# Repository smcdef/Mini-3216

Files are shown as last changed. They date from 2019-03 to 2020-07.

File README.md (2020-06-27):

# MINI 3216 电子时钟









还记得5年前（2014年）刚入门51单片机的时候的学习场景。当年单片机的学习之路是跟着杜洋的《爱上单片机》一书学习。如今这本书都已经出到第四版了（推荐一下这本书，还是很不错的，图片和制作都很用心）。那时候就很喜欢这本书里面的电子制作。杜老师有很多的电子DIY作品，唯一让我感兴趣的就是Mini 3216。这是一个电子时钟。非常的有意思。刚学习单片机的时候就励志以后一定也做个一模一样的时钟(当年的志向就是那么的简单)。

但是当我真的开始琢磨时，发现事情并不是那么的简单。如此简单的电路是如何使用单片机的32个IO驱动 32 x 16 点阵的呢？我们知道32个IO口驱动点阵的极限是16x16点阵。很是好奇，经过自己的琢磨终于想明白了原理。我们使用32个IO口连接16x16点阵，则没有任何问题。另外16x16点阵如何处理呢？反接吧！描述的不清还是看下原理图。如果下面的原理图依然看不明白，就看下PDF的原理图（pcb/mini3216时钟V3.0.PDF）。硬件虽然是连接起来了，软件又该如何处理呢？STC单片机的IO口可以设置4种模式，分别是：普通IO、推挽输出、高祖输入和开漏。为了让一个LED的亮度正常显示，我们利用推挽输出20mA电流驱动LED。为了驱动的时候不影响其他的LED，我们还需要将不需要点亮的LED的IO口设置开漏模式。这样就OK了。

```txt
        P0 <--------+------------+
                    |   +-----+  |   +-----+
                    +---+  0  |  +---+  2  |
                        +--+--+      +--+--+
                           |            |
          +----------------+            +-------+
          |                                     |
          |  P2 <---+------------+              |
          |         |   +-----+  |   +-----+    |
          |         +---+  1  |  +---+  3  |    |
          |             +--+--+      +--+--+    |
          |                |            |       |
          +----------------+            +-------+
          |                                     |
          v                                     v
          P3                                    P4

         P3 <-------+------------+
                    |   +-----+  |   +-----+
                    +---+  4  |  +---+  6  |
                        +--+--+      +--+--+
                           |            |
          +----------------+            +-------+
          |                                     |
          |  P4 <---+------------+              |
          |         |   +-----+  |   +-----+    |
          |         +---+  5  |  +---+  7  |    |
          |             +--+--+      +--+--+    |
          |                |            |       |
          +----------------+            +-------+
          |                                     |
          v                                     v
          P0                                    P2
```

关注这款时钟实现原理的朋友，好奇的问题一定是如何驱动 32 x 16 点阵。这部分代码实现位于core/fb_core.c文件。

于是就开始了自己的DIY之旅。虽然很多年过去了，Mini 3216已经陪伴了我4个春秋。摆在电脑旁边，也是一种享受。整点时刻会小声滴滴几下，提醒着我时间的流逝。有人说电脑右下角不是有时间嘛！是啊！就当我近似看不清，我就是喜欢字体大点的😄。

而现在我依稀发现，网上还是没有人公开原理（可能感兴趣的人不多）。虽然大学毕业后并没有从事单片机行业，但是依然保持对单片机的热爱。也由于自己工作接触的软件多为开源软件。因此，自己也有一颗开源的心。希望分享给更多的人。

## 优点

1. 所有元器件都在PCB top layout，最终焊接后都会藏在点阵屏下面，美观简介。
2. 高精度时钟芯片DS3231SN，一年误差30秒之内（数据来自DS3231 Datasheet），时间更精准。
3. 支持 -20℃~60℃环境温度显示。
4. 全方位检测环境光强，环境暗时，自动降低亮度（3级亮度自动调节）。
5. 上下左右4个Micro USB接口，方便供电。
6. 具有整点报时功能，报时声音采用新闻联播7:00开始前的多段声音报时。
7. 具有独特重力换向功能，不止可以正着放，还可以倒着放，显示内容总是正向的（想象你的手机横屏功能）。
8. 内置备用电池可保证断电后上电时间依然正确。
9. 背面3个触摸按键，看起来就很高大上。
10. 主界面显示时间，每8s切换显示2s温度（如果你愿意，显示流动显示日期也不是问题啊）。
11. 5v, 40mA工作电流。粗略计算，不断电使用7个月消耗1度电。
12. 源码公开，可以愉快的DIY了。你得天下你做主。

## 效果展示

我个人是集齐了红、蓝、白、橙、绿等几种颜色。总得效果来说各个颜色都挺好看。各有特色。附上两张蓝色显示效果图。

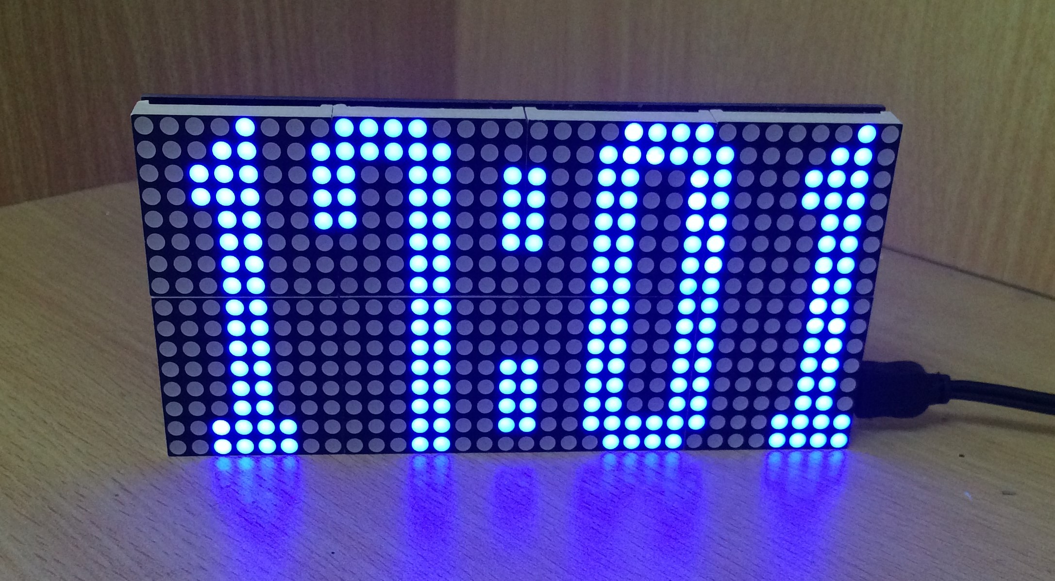
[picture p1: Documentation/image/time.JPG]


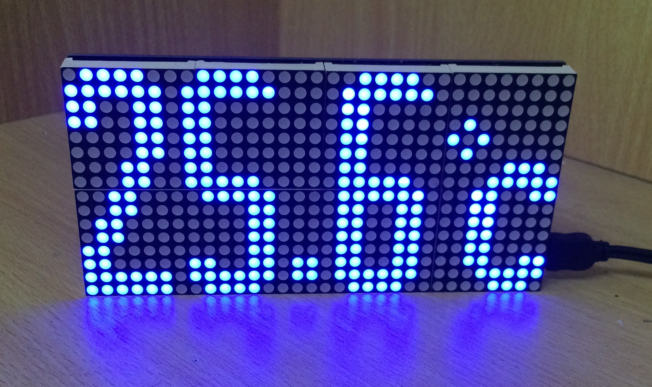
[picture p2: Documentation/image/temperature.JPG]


硬件经过几次改版，现在的硬件具有上下左右4个micro USB口，方便供电。上下左右4个光敏电阻全方位检测环境光强。背面3个触摸按键。PCB top layout 和 bottom layout 展示如下图所示。

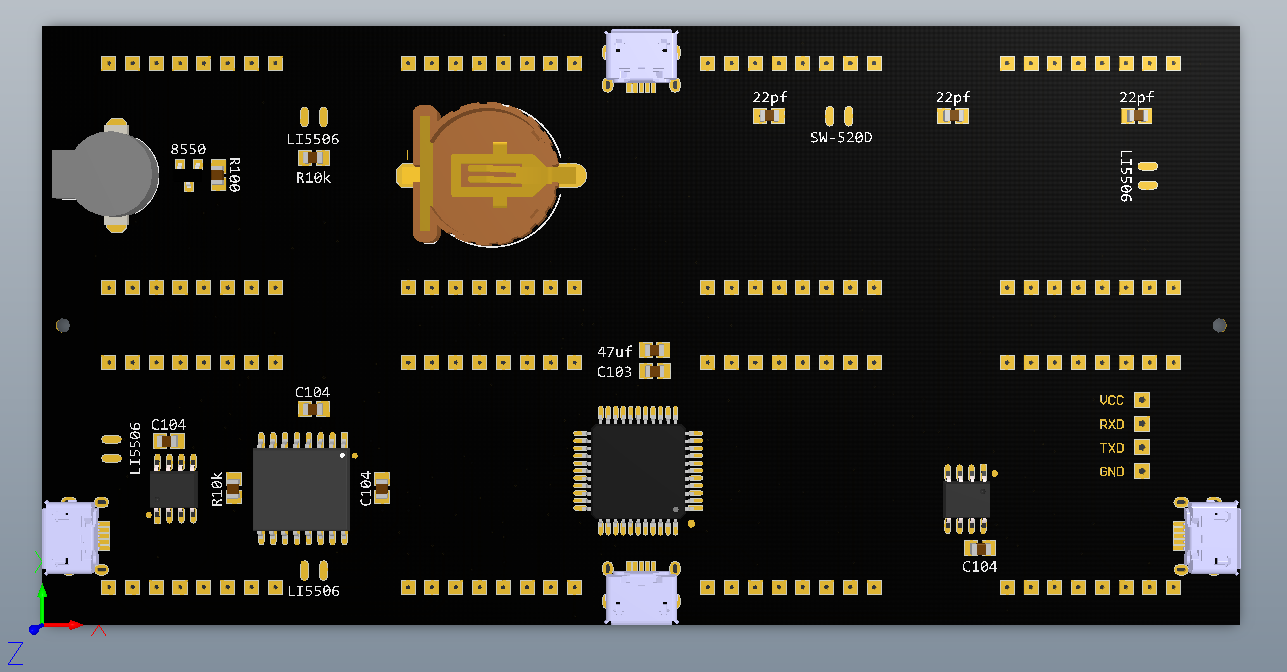
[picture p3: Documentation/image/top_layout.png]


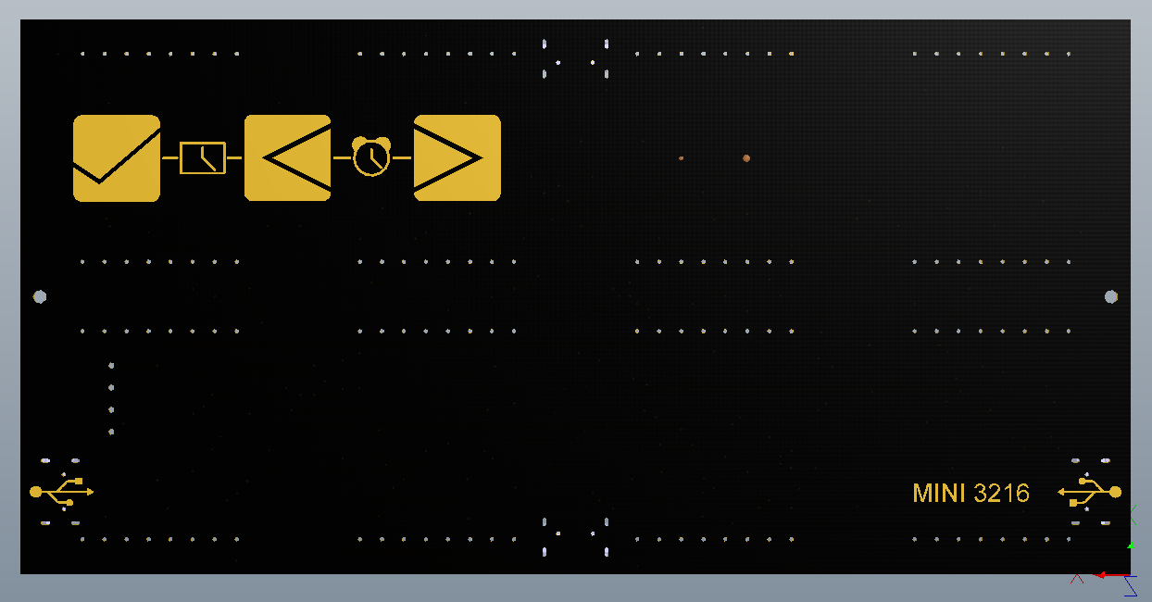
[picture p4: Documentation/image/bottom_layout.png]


## 元器件清单

| 元器件 | 数量 |
| :--- | ---: |
| 47uF 0805电容 | 1 |
| 10nF 0805电容 | 1 |
| 100nF 0805电容 | 4 |
| CR1220 | 1 |
| CR1220电池座 | 1 |
| [平口micro USB](https://item.taobao.com/item.htm?spm=a1z09.2.0.0.56db2e8d9M883Y&id=563928996432&_u=o1ltpbj55c9c) | 4 |
| [圆孔单排排母](https://item.taobao.com/item.htm?spm=a1z10.3-c.w4002-21261304145.10.1f211f35uFoswJ&id=564032495761) | 4 |
| [SW-520D倾角开关](https://detail.tmall.com/item.htm?id=580815564872&spm=a1z09.2.0.0.56db2e8d9M883Y&_u=o1ltpbj5179b) | 1 |
| 10k 欧姆0805电阻 | 2 |
| 100 欧姆0805电阻 | 1 |
| 22pF 0805电容 | 3 |
| LM75温度传感器 | 1 |
| [BS813A触摸芯片](https://item.taobao.com/item.htm?spm=a1z09.2.0.0.56db2e8d9M883Y&id=36285536377&_u=o1ltpbj5139d) | 1 |
| PNP S8550三极管 | 1 |
| 光敏电阻5506 | 4 |
| DS3231SN时钟芯片 | 1 |
| [KLJ-9032蜂鸣器](https://item.taobao.com/item.htm?spm=a1z09.2.0.0.56db2e8d9M883Y&id=564040278829&_u=o1ltpbj5673d) | 1 |
| [32mm 共阳点阵（上下各8个引脚，引脚间距2.54mm）](https://item.taobao.com/item.htm?spm=a1z09.2.0.0.56db2e8d9M883Y&id=573348473815&_u=o1ltpbj52711) | 8 |
| STC15F2K60S2单片机 | 1 |
| [1x4单排排母（下载接口使用）](https://item.taobao.com/item.htm?spm=a1z10.3-c.w4002-21261304145.9.51231f35z1KhNQ&id=563776620907) | 1 |

## 技术规格

工作电压：DC 5V

工作电流：40mA

功      率：0.2W（低功耗）

外形尺寸：128x11x64 mm

工作温度：-20℃~60℃

点阵型号：F3.0  1388点阵

## 更新说明

1. PCB由BS814A更改为BS813A（代码配置CONFIG_BS813A）。
2. 增加DS3231中断引脚连接。
3. 光敏电阻一端增加10k上拉电阻。

## 注意事项

1. 单片机使用的是STC15F2K60S2，使用内部晶振
2. 下载时，晶振频率请选择27MHz
3. 初次构建Keil工程后，请如下设置。
    - 快捷键**Alt+F7**进入Options for Target ‘Target 1’设置界面。
    - 点击**Device**选项框，勾选**Use Extended Linker(LX51) instead of BL51**。
    - 点击**LX51 Misc**选项框，在Misc controls输入栏填写**REMOVEUNUSED**。
    - 点击**OK**，设置完成。
4. 默认情况下，初次下载程序后，当断开主电源后DS3231默认不工作（备份电池省电，可以不使用后长时间放置）。当需要使用时候，需要按下背部3个按键。因此，当你发现断电后下次上电时间没有保存，请先按下3个按键尝试设置。如果设置不起效，可能原因是纽扣电池没电了，请更换电池。
5. 如果你是用Mac烧写单片机，可以选择stcgal工具。运行命令： `make flash`
6. 强烈建议使用Keil C51编译源码，实测发现Keil C51对代码的优化效果远好于SDCC。hex目录下已经为你准备一份Keil C51编译的hex镜像。

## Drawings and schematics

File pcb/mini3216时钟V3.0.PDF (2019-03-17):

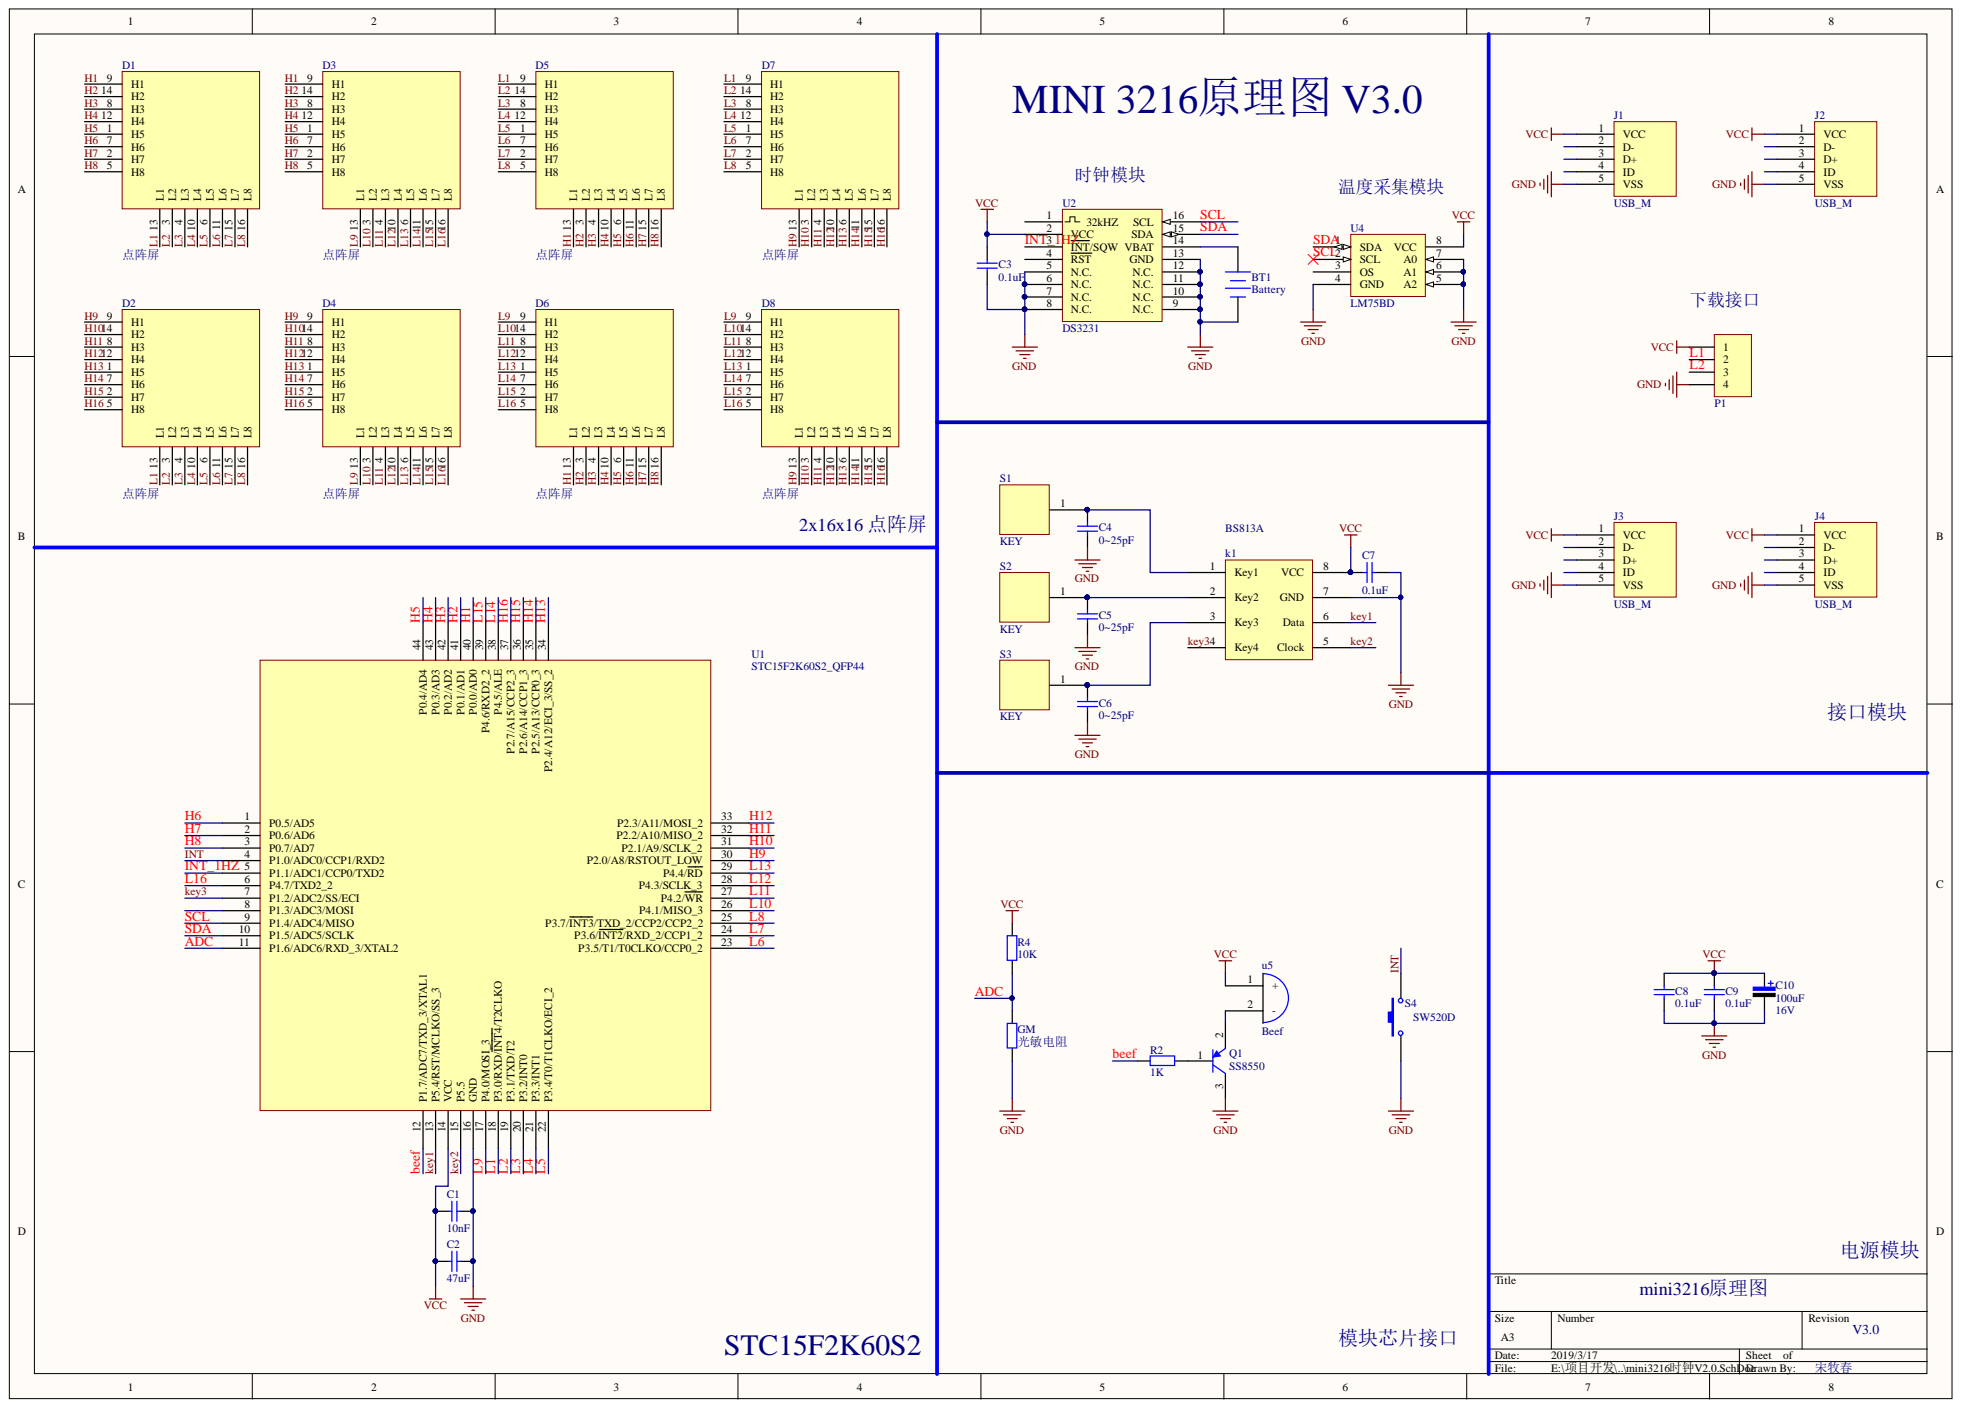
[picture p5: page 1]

Size A3 | Number | Revision V3.0

Date: 2019/3/17 | Sheet of
File: E:\项目开发\..\mini3216时钟V2.0.SchDocDrawn By: | 宋牧春

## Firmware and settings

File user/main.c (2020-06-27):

/**
 * Core interface implementation for Mini3216.
 *
 * Copyright (c) 2019-2020  smcdef.
 *
 * Author: songmuchun <smcdef@163.com>
 *
 * This program is free software; you can redistribute it and/or modify
 * it under the terms of the GNU General Public License as published by
 * the Free Software Foundation; either version 2 of the License, or
 * (at your option) any later version.
 */

#include "fb_core.h"
#include "fb_mem.h"
#include "config.h"
#include "font.h"
#include "adc.h"
#include "eeprom.h"
#include "ds3231.h"
#include "i2c.h"
#include "usart.h"
#include "lm75.h"
#include "touch_key.h"
#include "delay.h"
#include "timer.h"
#include "buzzer.h"
#include <string.h>

#define is_rotate P1_0

struct set_time_env {
	char key;
	char max;
	char min;
	enum set_type type;
	const char *name;
	struct fb_info xdata *fb_info;
};

struct menu {
	const char *name;
	struct menu xdata *child;
	struct menu xdata *sibling_next, *sibling_prev;
	void xdata *private;
	void (func_prt_type *operate)(void xdata *private);
	unsigned int (func_prt_type *fb_load)(unsigned int offset);
};

struct user_data {
	struct rtc rtc;
	struct fb_info fb_info;
	bool night_mode;
	struct {
		unsigned char brightness;
		bool oscillator_on;
	} settings;
	bool fb_update;
	char key;
};

static struct menu xdata root_menu;
static struct menu xdata set_hour_menu;
static struct menu xdata set_minute_menu;
static struct menu xdata *current;

static struct user_data xdata user_data;

static void local_irq_disable(void)
{
	EA = 0;
}

static void local_irq_enable(void)
{
	EA = 1;
}

static bool rtc_update = true;

static bool rtc_update_set_return(bool update)
{
	bool updated;

	local_irq_disable();
	updated = rtc_update;
	rtc_update = update;
	local_irq_enable();

	return updated;
}

static void rtc_update_set_irq(bool update)
{
	rtc_update = update;
}

static void user_data_init(void)
{
	memset(&user_data, 0, sizeof(user_data));
	user_data.fb_info.fair = false;
	user_data.fb_info.rotate = !is_rotate;
	user_data.fb_update = true;
	rtc_update_set_return(true);
	eeprom_read(EEPROM_SECTOR1_ADDR, &user_data.settings,
		    sizeof(user_data.settings));

	if (user_data.settings.brightness > CONFIG_MAX_BRIGHTNESS ||
	    user_data.settings.oscillator_on > 1) {
		user_data.settings.brightness = CONFIG_MAX_BRIGHTNESS;
		user_data.settings.oscillator_on = false;
		eeprom_write(EEPROM_SECTOR1_ADDR, &user_data.settings,
			     sizeof(user_data.settings));
	}

	ds3231_enable_oscillator(user_data.settings.oscillator_on);
	user_data.fb_info.brightness = user_data.settings.brightness;
}

static void pca_init(void)
{
	CCON	= 0;
	CL	= 0;
	CH	= 0;
	CMOD	= 0x00;
	CCAPM0	= 0x21;		/* Rising edge */
	CCAPM1	= 0x31;		/* Rising and falling edges */
	CR	= 1;
}

static unsigned int fb_load_temperature(unsigned int offset)
{
	char xdata str[] = " - - . - c";
	char integer, decimals;
	char xdata *p = str + 1;

	if (lm75_read_temperature(&integer, &decimals) &&
	    ds3231_read_temperature(&integer, &decimals))
		goto err;

	if (integer > -10) {
		if (integer > 9)
			str[1] = integer / 10 + '0';
		else if (integer >= 0)
			str[1] = NONE_ASCII;
		else
			integer = ~integer + 1;

		str[3] = integer % 10 + '0';
		str[7] = decimals / 10 + '0';
	} else {
		integer = ~integer + 1;
		str[1] = ' ';
		str[5] = integer / 10 + '0';
		str[7] = integer % 10 + '0';
		p = str;
	}
err:
	return fb_copy_string(offset, p);
}

static bool should_show_temperature(struct user_data xdata *user)
{
	return !user->night_mode;
}

static bool should_chime(struct rtc *rtc)
{
	return rtc->sec == 0x58 &&
	       rtc->min == 0x59 &&
	       rtc->hour >= DEC_TO_BCD(CONFIG_CHIME_START_HOUR - 1) &&
	       rtc->hour < DEC_TO_BCD(CONFIG_CHIME_END_HOUR);
}

static void show_times(void xdata *priv)
{
	static char sec_old = -1, min_old = -1, hour_old = -1;
	struct user_data xdata *user = priv;
	struct rtc xdata *rtc = &user->rtc;
	struct fb_info xdata *fb_info = &user->fb_info;
	bool force = user->fb_update;
	char xdata str[5];
	char half_low;
	static bool is_temp = false;
	unsigned int offset = 0;

	if (!rtc_update_set_return(false))
		return;

	if (ds3231_read_times(rtc))
		return;

	if (sec_old == rtc->sec && !force)
		return;
	sec_old = rtc->sec;

	if (force) {
		fb_info->offset = 0;
		user->fb_update = false;
		is_temp = false;
	}

	if (is_temp)
		goto skip_load;

	if (should_chime(rtc) && !user->night_mode)
		buzzer_chime();

	if (hour_old != rtc->hour || force) {
		hour_old = rtc->hour;
		str[0] = hour_old / 16 + '0';
		str[1] = ' ';
		str[2] = hour_old % 16 + '0';
		str[3] = ' ';
		str[4] = '\0';
		offset += fb_copy_string(offset, str);
	} else {
		offset += 14;
	}

	if (sec_old & BIT(0))
		str[0] = '^';
	else
		str[0] = 'v';
	str[1] = ' ';
	str[2] = '\0';
	offset += fb_copy_string(offset, str);

	if (min_old != rtc->min || force) {
		min_old = rtc->min;
		str[0] = min_old / 16 + '0';
		str[1] = ' ';
		str[2] = min_old % 16 + '0';
		str[3] = '\0';
		offset += fb_copy_string(offset, str);
	} else {
		offset += 13;
	}

skip_load:
	half_low = sec_old & 0x0f;
	if (half_low > 2 && half_low < 5 && should_show_temperature(user)) {
		if (!is_temp) {
			unsigned char brightness;

			/**
			 * fb_info->brightness maybe alter in irq.
			 * So we should disable irq to protect shared
			 * variable.
			 */
			local_irq_disable();
			/**
			 * Re-check under disable irq.
			 */
			if (!should_show_temperature(user)) {
				local_irq_enable();
				return;
			}
			brightness = fb_info->brightness;
			fb_info->brightness = CONFIG_SCAN_SPEED_BRIGHTNESS;
			fb_load_temperature(offset);
			fb_info->offset += fb_scan(fb_info, 64, 1);
			fb_info->brightness = brightness;
			local_irq_enable();
			is_temp = true;
		}
	} else if (is_temp) {
		unsigned char brightness;

		/**
		 * fb_info->brightness maybe alter in irq.
		 * So we should disable irq to protect shared
		 * variable.
		 */
		local_irq_disable();
		brightness = fb_info->brightness;
		/**
		 * If we are in night mode, we should not increase
		 * the brightness.
		 */
		if (!user->night_mode)
			fb_info->brightness = CONFIG_SCAN_SPEED_BRIGHTNESS;
		fb_info->offset += fb_scan_reverse(fb_info, 64, 1);
		fb_info->brightness = brightness;
		local_irq_enable();
		is_temp = false;
	}
}

static unsigned int fb_load_time(unsigned int offset, enum set_type type,
				 const char *s)
{
	char value;
	unsigned int offset_old = offset;
	char xdata str[] = "  - - ";

	if (ds3231_read_time(type, &value))
		return 0;

	str[2] = value / 16 + '0';
	str[4] = value % 16 + '0';
	offset += fb_copy_string(offset, str);
	offset += fb_copy_string(offset, s);

	return offset - offset_old;
}

static unsigned int fb_load_hour(unsigned int offset)
{
	return fb_load_time(offset, SET_HOUR, "时");
}

static unsigned int fb_load_minute(unsigned int offset)
{
	return fb_load_time(offset, SET_MINUTES, "分");
}

static unsigned int fb_load_hour_and_minute(unsigned int offset)
{
	struct rtc xdata rtc;
	char xdata str[10];

	if (ds3231_read_times(&rtc))
		return offset;

	str[0] = rtc.hour / 16 + '0';
	str[1] = ' ';
	str[2] = rtc.hour % 16 + '0';
	str[3] = ' ';

	if (rtc.sec & BIT(0))
		str[4] = '^';
	else
		str[4] = 'v';
	str[5] = ' ';

	str[6] = rtc.min / 16 + '0';
	str[7] = ' ';
	str[8] = rtc.min % 16 + '0';
	str[9] = '\0';

	return fb_copy_string(offset, str);
}

static void key_delay(struct fb_info *fb_info)
{
	char i;

	buzzer_key();
	for (i = 0; i < 20; i++)
		fb_show(fb_info);
}

static bool set_time_common(struct set_time_env xdata *env)
{
	char value;
	enum set_type type = env->type;
	struct fb_info xdata *fb_info = env->fb_info;

	if (ds3231_read_time(type, &value))
		return false;
	value = BCD_TO_DEC(value);

	switch (env->key) {
	case KEY_RIGHT:
		if (++value > env->max)
			value = env->min;
		key_delay(fb_info);
		break;
	case KEY_LEFT:
		if (--value < env->min)
			value = env->max;
		key_delay(fb_info);
		break;
	default:
		return false;
	}

	ds3231_set_time(type, DEC_TO_BCD(value));
	fb_load_time(fb_info->offset, type, env->name);

	return true;
}

static void set_hour(void xdata *priv)
{
	struct user_data xdata *user = priv;
	struct set_time_env xdata env;

	env.key		= user->key;
	env.max		= 23;
	env.min		= 0;
	env.type	= SET_HOUR;
	env.name	= "时";
	env.fb_info	= &user->fb_info;

	if (!set_time_common(&env)) {
		if (!rtc_update_set_return(false))
			return;
		fb_load_hour(user->fb_info.offset);
	}
}

static void set_minute(void xdata *priv)
{
	struct user_data xdata *user = priv;
	struct set_time_env xdata env;

	env.key		= user->key;
	env.max		= 59;
	env.min		= 0;
	env.type	= SET_MINUTES;
	env.name	= "分";
	env.fb_info	= &user->fb_info;

	if (!set_time_common(&env)) {
		if (!rtc_update_set_return(false))
			return;
		fb_load_minute(user->fb_info.offset);
		return;
	}
	ds3231_set_time(SET_SECOND, 0);
}

#define ROOT_MENU_NAME		"root"

static bool is_root_menu(struct menu xdata *entry)
{
	return entry->name && !strcmp(entry->name, ROOT_MENU_NAME);
}

static void menu_init(void)
{
	memset(&root_menu, 0, sizeof(root_menu));
	root_menu.name = ROOT_MENU_NAME;
	/* root_menu.child = &set_hour_menu; */
	root_menu.private = &user_data;
	root_menu.fb_load = fb_load_hour_and_minute;
	root_menu.operate = show_times;

	memset(&set_hour_menu, 0, sizeof(set_hour_menu));
	set_hour_menu.private = &user_data;
	set_hour_menu.child = &set_minute_menu;
	set_hour_menu.fb_load = fb_load_hour;
	set_hour_menu.operate = set_hour;

	memset(&set_minute_menu, 0, sizeof(set_minute_menu));
	set_minute_menu.private = &user_data;
	set_minute_menu.child = &root_menu;
	set_minute_menu.fb_load = fb_load_minute;
	set_minute_menu.operate = set_minute;

	current = &root_menu;
}

static bool interface_switching(struct user_data xdata *user, char key)
{
	struct fb_info xdata *fb_info = &user->fb_info;
	struct menu xdata *current_old = current;
#if CONFIG_FB_SIZE > 128
	unsigned int offset;
#endif

	switch (key) {
	case KEY_ENTER:
		if (is_root_menu(current) || !current->child)
			break;

		buzzer_enter();
		current = current->child;
		if (is_root_menu(current)) {
			rtc_update_set_return(true);
			user->fb_update = true;
		}

		if (current->fb_load)
			current->fb_load(fb_info->offset + MATRIXS_COLUMNS);
		else
			fb_copy_string(fb_info->offset + MATRIXS_COLUMNS,
				       current->name);
		fb_info->offset += fb_scan(fb_info, 64,
					  CONFIG_SETTING_SCAN_SPEED);
		break;
	case KEY_LEFT:
		if (!current->sibling_prev)
			break;
		buzzer_key();
		fb_copy_string(fb_info->offset - MATRIXS_COLUMNS,
					current->sibling_prev->name);
		fb_info->offset += fb_scan_reverse(fb_info, 64,
						  CONFIG_SETTING_SCAN_SPEED);
		current = current->sibling_prev;
		break;
	case KEY_RIGHT:
		if (!current->sibling_next)
			break;
		buzzer_key();
		fb_copy_string(fb_info->offset + MATRIXS_COLUMNS,
				current->sibling_next->name);
		fb_info->offset += fb_scan(fb_info, 64,
					  CONFIG_SETTING_SCAN_SPEED);
		current = current->sibling_next;
		break;
	case KEY_LEFT | KEY_RIGHT:
		/* special for root menu and enter the settings menu */
		if (!is_root_menu(current))
			break;

		if (!current->child)
			break;
		buzzer_enter();
		current = current->child;
		fb_copy_string(fb_info->offset + MATRIXS_COLUMNS,
				current->name);
		fb_info->offset += fb_scan(fb_info, 64,
					  CONFIG_SETTING_SCAN_SPEED);
		break;
	case KEY_LEFT | KEY_ENTER:
		/* special for root menu and enter the setup time menu */
		if (!is_root_menu(current))
			break;

		buzzer_enter();
		current = &set_hour_menu;
#if CONFIG_FB_SIZE > 128
		offset = fb_info->offset + MATRIXS_COLUMNS;
		offset += fb_copy_string(offset, "设置时间");
		if (current->fb_load)
			offset += current->fb_load(offset);
		fb_info->offset = fb_scan(fb_info, 128,
					  CONFIG_SEETING_TIME_SCAN_SPEED);
#else
		fb_info->offset += fb_scan_string(fb_info, MATRIXS_COLUMNS,
						  CONFIG_SEETING_TIME_SCAN_SPEED,
						  "设置时间");
		if (current->fb_load)
			current->fb_load(fb_info->offset + MATRIXS_COLUMNS);
		fb_info->offset += fb_scan(fb_info, 64,
					  CONFIG_SEETING_TIME_SCAN_SPEED);
#endif
		break;
	case KEY_LEFT | KEY_RIGHT | KEY_ENTER:
		/* special for root menu and enable/disable oscillator */
		if (!is_root_menu(current))
			break;

		if (user->settings.oscillator_on)
			break;
		user->settings.oscillator_on = true;
		eeprom_write(EEPROM_SECTOR1_ADDR, &user->settings,
			     sizeof(user->settings));
		ds3231_enable_oscillator(true);
		buzzer_enter();
		return true;
	default:
		return false;
	}

	return current_old != current;
}

void main(void)
{
	struct fb_info xdata *fb_info = &user_data.fb_info;

	local_irq_disable();
	user_data_init();
	buzzer_power_on();
	uart_init();
	touch_key_init();
	fb_init();
	i2c_init();
	ds3231_init();
	font_sort();
	menu_init();
	pca_init();
	adc_init(CONFIG_PRES_ADC_CHANNEL);
	timer0_init();
	timer1_init();
	local_irq_enable();

	while (1) {
		if (touch_key_read(&user_data.key)) {
			bool success = interface_switching(&user_data,
							   user_data.key);

			while (success && touch_key_read(&user_data.key))
				fb_show(fb_info);
		}
		if (current && current->operate)
			current->operate(current->private);

		/**
		 * We should disable local irq when call fb_show().
		 * But we can not do this, because if we do that,
		 * the buzzer_chime() will work abnormal. And now
		 * we can do that. Because timer0 is not able to
		 * mask interrupts via EA = 0.
		 */
		local_irq_disable();
		fb_show(fb_info);
		local_irq_enable();
	}
}

/* Timer1 interrupt routine(10ms) */
void timer1_isr() interrupt 3 using 2
{
	static unsigned char timer_count = 0;

	/* every 160ms */
	if (timer_count % 16 == 0)
		adc_start(CONFIG_PRES_ADC_CHANNEL);

	timer_count++;
}

#define NIGHT_MODE_ADC_VALUE		0xa0
#define BRIGHT_MODE_ADC_VALUE		0x60

/* ADC interrupt routine */
void adc_isr(void) interrupt 5 using 1
{
	unsigned char result;

	ADC_CONTR &= ~ADC_FLAG;
	result = ADC_RES;
	if (result > NIGHT_MODE_ADC_VALUE) {
		user_data.night_mode = true;
		user_data.fb_info.fair = CONFIG_NIGHT_MODE_FAIR_FACTOR;
		user_data.fb_info.brightness = CONFIG_NIGHT_MODE_BRIGHTNESS;
	} else if (result > BRIGHT_MODE_ADC_VALUE) {
		user_data.night_mode = true;
		user_data.fb_info.brightness = CONFIG_NIGHT_MODE_BRIGHTNESS;
		user_data.fb_info.fair = false;
	} else if (user_data.night_mode) {
		user_data.night_mode = false;
		user_data.fb_info.brightness = user_data.settings.brightness;
		user_data.fb_info.fair = false;
	}
}

void pca_isr(void) interrupt 7 using 2
{
	if (CCF0) {
		CCF0 = 0;
		rtc_update_set_irq(true);
	}

	if (CCF1) {
		CCF1 = 0;
		user_data.fb_info.rotate = !is_rotate;
	}
}

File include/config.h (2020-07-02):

/**
 * All configuration options.
 *
 * Copyright (c) 2019-2020  smcdef.
 *
 * Author: songmuchun <smcdef@163.com>
 *
 * This program is free software; you can redistribute it and/or modify
 * it under the terms of the GNU General Public License as published by
 * the Free Software Foundation; either version 2 of the License, or
 * (at your option) any later version.
 */

#ifndef __CONFIG_H
#define __CONFIG_H

#define CONFIG_FB_SIZE_SHIFT			7
/**
 * CONFIG_FB_SIZE must be 2 to the power of n. Also, it should greater than or
 * equal to 128. For example 128, 256, 512, 1024 or 2048...
 */
#define CONFIG_FB_SIZE				(1 << CONFIG_FB_SIZE_SHIFT)
/* system main clock */
#define CONFIG_MAIN_FOSC			27000000L
#define CONFIG_BS813A
#define CONFIG_PRES_ADC_CHANNEL			6
#define CONFIG_MAX_BRIGHTNESS			80
#define CONFIG_NIGHT_MODE_BRIGHTNESS		1
#define CONFIG_NIGHT_MODE_FAIR_FACTOR		55
#define CONFIG_SCAN_SPEED_BRIGHTNESS		55
#define CONFIG_SEETING_TIME_SCAN_SPEED		15
#define CONFIG_SETTING_SCAN_SPEED		2
#define CONFIG_CHIME_START_HOUR			8
#define CONFIG_CHIME_END_HOUR			22

#if CONFIG_FB_SIZE_SHIFT < 7
#error "CONFIG_FB_SIZE_SHIFT should greater than or equal to 7"
#endif

#if CONFIG_PRES_ADC_CHANNEL > 7 || CONFIG_PRES_ADC_CHANNEL < 0
#error "CONFIG_PRES_ADC_CHANNEL should be less than or equal to 0 or \
	greater than or equal to 7"
#endif

#if defined (SDCC) || defined (__SDCC)
#define xdata		__xdata
#define pdata		__pdata
#define idata		__idata
#define code		__code
#define bit		__bit
#define interrupt	__interrupt
#define using		__using
#define func_prt_type
#else
#define func_prt_type	code
#define inline
#endif

#endif

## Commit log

2019-03-09 add base hardware driver
2019-03-09 add PCB and SchDoc
    [mini3216时钟V2.0.SchDoc]
2019-03-09 clear uart code
2019-03-09 fix int to char in matrix##n##_disp()
    [fb_core.c]
2019-03-10 add buzzer driver
2019-03-10 fix can not read time via ds3231_read_time()
    [ds3231.c]
2019-03-10 Change ADC acquisition period from 100ms to 200ms
2019-03-14 add new api to control oscillator
    [ds3231.c]
2019-03-16 fix unevent scan speed when time switchs temperature and increase brightness
    [main.c]
2019-03-16 update PCB
    [mini3216时钟V2.0.SchDoc]
2019-03-16 fix flicker when 08:08
    [main.c]
2019-03-17 add BS813A driver
2019-03-17 remove ADC #define from adc.h to adc.c
2019-03-19 add a new configuration CONFIG_FB_SIZE in order to configure the size of frame buffer
2019-03-20 fix array is not initialized to 'c'
    [fb_core.c]
2019-03-20 fix maybe increase brightness when in night mode
    [main.c]
2019-03-20 fix not enable irq when return in fb_load_times()
    [main.c]
2019-03-21 fix pass error offset parameter
    [main.c]
2019-03-22 change uart timer1 to timer2
2019-03-24 Disable local irq when call fb_show()
    Now we can disable local irq before call fb_show(). Because timer0 is
    not able to mask interrupts via EA = 0.
2019-03-24 Use idata for frame buffer when FB_SIZE is 128
2019-03-24 Fix NULL pointer reference in is_root_menu()
    [main.c]
2019-03-24 Modify ADC acquisition period from 200ms to 320ms
2019-03-24 fix code style problem
    [fb_core.c]
2019-03-24 Resize frame buffer size to 256
    Now 256 is enough. So resize frame buffer size to increase
    speed of read/write fb(pdata is faster than xdata). Because
    pdata memory size is only 256 bytes, we have to modify the
    memory areas of other variables to the memory area of idata.
2019-03-24 Replace a simple way to initialize the string array
    [main.c]
2019-03-24 Fix resize frame buffer size to 256
    Fixes: 56b98b560edc (Resize frame buffer size to 256)
    [config.h]
2019-03-24 Fix time cannot be set correctly when evn->min is not 0
    [main.c]
2019-03-24 Replace the constant with the macro MATRIXS_COLUMNS
    [fb_core.c]
2019-03-25 Replace 'FB_SIZE / 2' with FB_COLUMNS
    [fb_core.c]
2019-03-25 Change ADC acquisition period from 320ms to 1280ms
2019-03-26 Optimize the driver of the dot matrix screen
2019-03-26 Fix forgot to call buzzer_power_on()
    [main.c]
2019-03-27 Replace '1 << i' with macro of BIT()
    [fb_core.c]
2019-03-27 Replace constants with macro
    [fb_core.c]
2019-03-27 Replace some mask with macro BIT() or GENMASK()
    [i2c.c]
2019-03-27 Add the core, include and drivers folders and remove the hardware
2019-03-27 Fix comment in fb_show()
    [fb_core.c]
2019-03-28 Fix led_on_delay() delay long time when fair < brightness
    [fb_core.c]
2019-03-30 Make RTC does not save time by default
    This means that every time you plug in the power, the time will be
    reset. If want that RTC save the time, you should press the 3 buttons
    on the back.
    [main.c]
2019-03-30 Call ds3231_enable_oscillator() every reboot
    [main.c]
2019-03-31 Wait for the button to release
2019-04-01 Prevent compiler warning for not using 'update'
    [main.c]
2019-04-01 Introduce rtc_update_set_irq() to prevent compiler warning
    If we call rtc_update_set_return() in pca_isr(), compiler
    will output the message "WARNING L15: MULTIPLE CALL TO FUNCTION".
    To prevent compiler warning, we introcduce a function named
    rtc_update_set_irq().
    [main.c]
2019-04-02 Fix return incorrent offset
    [main.c]
2019-04-02 Change ADC acquisition period from 1280ms to 160ms
2019-04-02 Replace idata with xdata
    [main.c]
2019-04-11 Revert "Remove CONFIG_SCAN_SPEED_BRIGHTNESS"
    This reverts commit b2064984f0d51d7e2c3a37358b3e61f33b7603c1.
    [config.h, main.c]
2020-06-27 Use idata for frame_buffer
